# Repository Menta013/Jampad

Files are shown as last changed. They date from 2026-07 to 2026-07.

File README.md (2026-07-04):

# Jampad

Jampad is a compact 3×3 mechanical macropad built around a through-hole
Seeed Studio XIAO RP2040. It includes an EC11 rotary encoder, a 0.91-inch
128×32 OLED, and a single SK6812 MINI-E status LED in a two-piece 3D-printed
enclosure.

## Project images

### Overall assembly and case

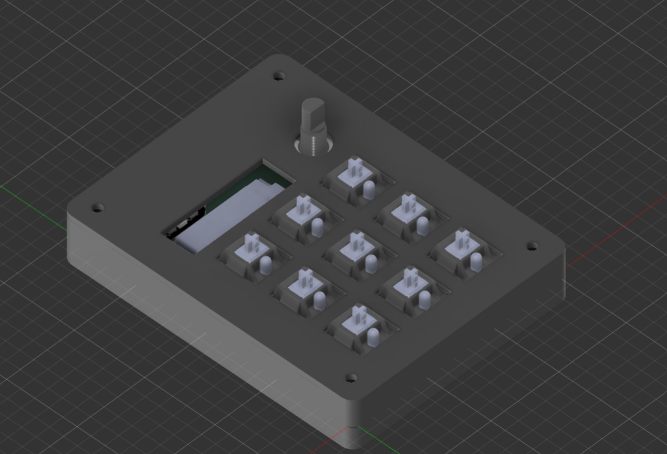
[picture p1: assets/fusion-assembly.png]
Jampad assembly in Fusion 360


### Bottom case

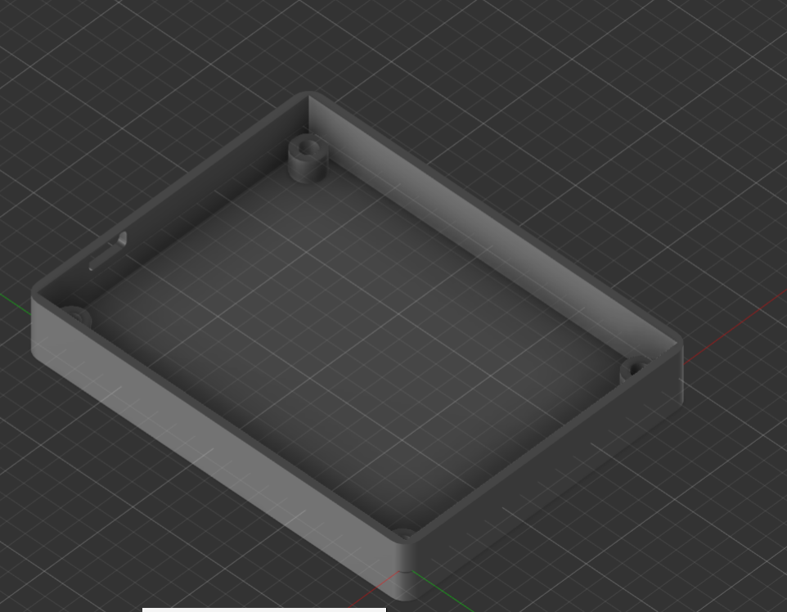
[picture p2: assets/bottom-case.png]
Jampad bottom case


### Top plate

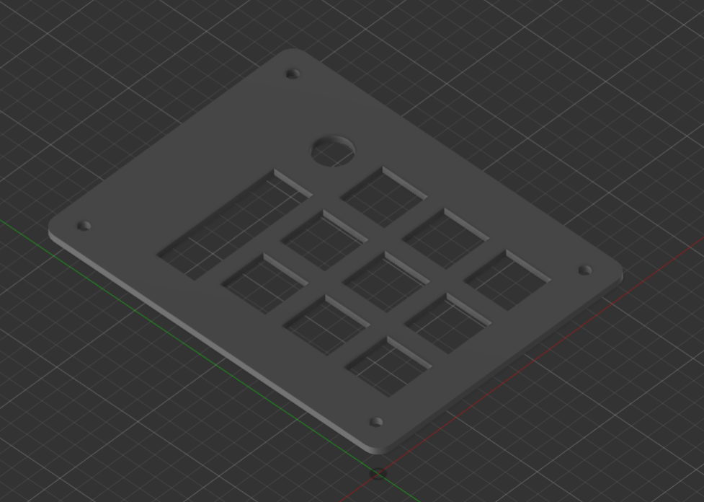
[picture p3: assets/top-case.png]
Jampad top plate


### Schematic

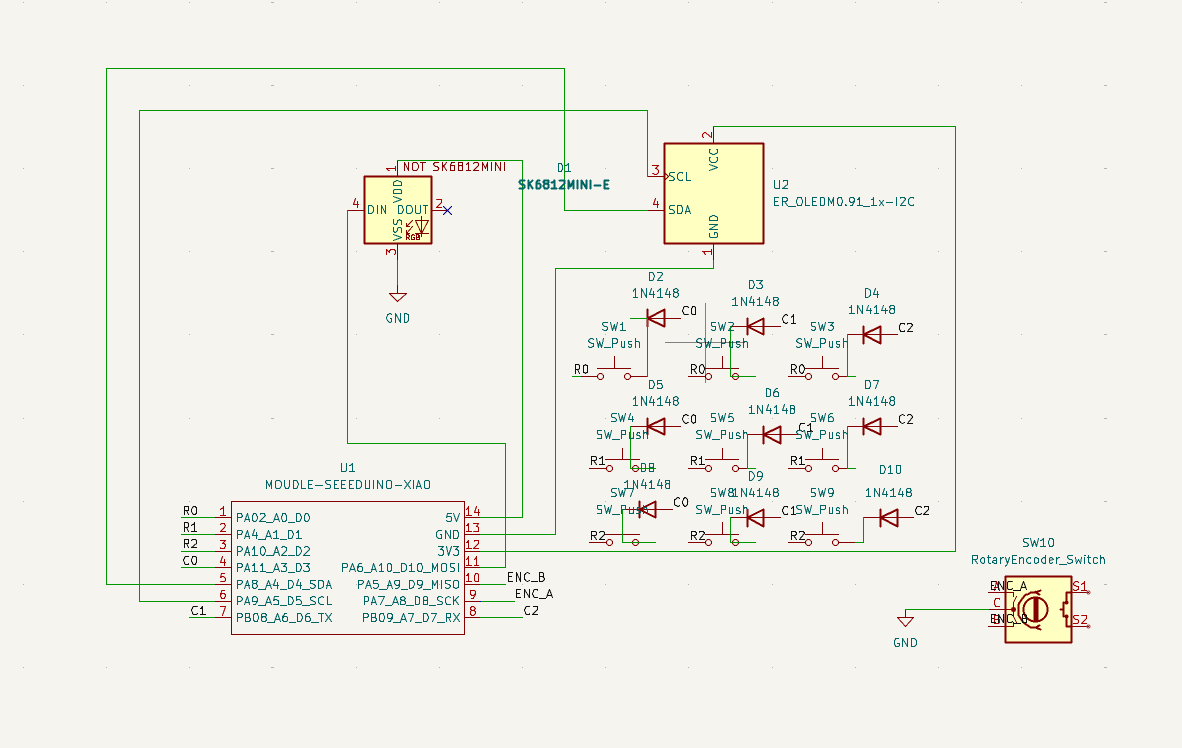
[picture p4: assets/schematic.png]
Jampad schematic


### PCB

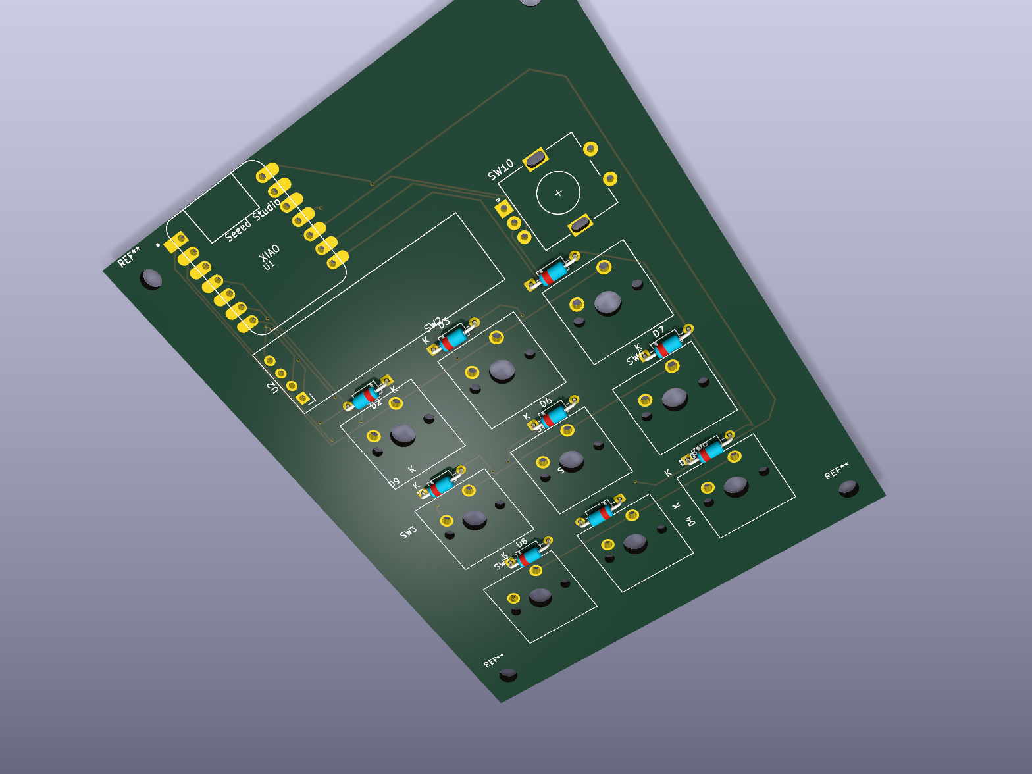
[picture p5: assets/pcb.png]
Jampad PCB render


## Default controls

| Undo | Copy | Paste |
|---|---|---|
| Previous track | Play/Pause | Next track |
| Escape | Windows screenshot | Delete |

The encoder controls system volume:

- Counter-clockwise: volume down
- Clockwise: volume up
- Press: unavailable because the encoder's `S1` and `S2` switch contacts are
  not connected in this PCB revision

## Hardware

- MCU: Seeed Studio XIAO RP2040
- Switches: 9× Cherry MX-compatible switches in a diode-protected 3×3 matrix
- Display: 0.91-inch SSD1306-compatible 128×32 I²C OLED
- Encoder: EC11-style quadrature rotary encoder
- Lighting: 1× SK6812 MINI-E addressable RGB LED
- PCB: two layers, approximately 76.2 × 99.54 mm
- Case: two-piece 3D-printed enclosure

## Firmware pin map

| Function | XIAO pin | RP2040 GPIO |
|---|---:|---:|
| Matrix row 0 | D0 | GP26 |
| Matrix row 1 | D1 | GP27 |
| Matrix row 2 | D2 | GP28 |
| Matrix column 0 | D3 | GP29 |
| OLED SDA | D4 | GP6 |
| OLED SCL | D5 | GP7 |
| Matrix column 1 | D6 | GP0 |
| Matrix column 2 | D7 | GP1 |
| Encoder A | D8 | GP2 |
| Encoder B | D9 | GP4 |
| SK6812 data | D10 | GP3 |

The matrix diode direction is `COL2ROW`.

## Bill of materials

| Quantity | Part | Notes |
|---:|---|---|
| 1 | Seeed Studio XIAO RP2040 | Through-hole mounted |
| 9 | MX-compatible mechanical switches | PCB-mount style |
| 9 | MX-compatible keycaps | 1U |
| 9 | 1N4148 through-hole diodes | Matrix diodes |
| 1 | EC11-style rotary encoder | Rotation is wired; push switch is not |
| 1 | Encoder knob | Sized for the selected shaft |
| 1 | 0.91-inch 128×32 I²C OLED | SSD1306-compatible, four pins |
| 1 | SK6812 MINI-E | Addressable RGB status LED |
| 1 | Custom two-layer PCB | Maximum 100 × 100 mm |
| 1 | 3D-printed top case | Production STEP included |
| 1 | 3D-printed bottom case | Production STEP included |
| 4 | M3×16 mm screws | Confirm final stack height before ordering |
| 4 | M3 heat-set inserts | Approximately 4 mm OD × 5 mm long |

## Repository structure

```text
Jampad_Submission/
├── CAD/          # Full assembly source/export goes here
├── PCB/          # KiCad source files
├── Firmware/     # QMK source
├── production/   # Manufacturing and flash files
└── assets/       # README screenshots
```

## Firmware build

Copy `Firmware/` to `qmk_firmware/keyboards/jampad/`, then run:

```sh
qmk compile -kb jampad -km default
```

The compiled firmware is included as `production/firmware.uf2`.

To flash it, hold the XIAO's **BOOT** button while connecting USB, then copy
`firmware.uf2` to the `RPI-RP2` drive.

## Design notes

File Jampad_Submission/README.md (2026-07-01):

# Jampad

Jampad is a compact 3×3 mechanical macropad built around a through-hole
Seeed Studio XIAO RP2040. It includes an EC11 rotary encoder, a 0.91-inch
128×32 OLED, and a single SK6812 MINI-E status LED in a two-piece 3D-printed
enclosure.

> **Fabrication status:** the nine switch-to-diode connections have been
> repaired. KiCad reports zero unconnected pads and no copper-clearance
> errors. Final Gerbers and drill files are included in
> `production/gerbers.zip`. Review the remaining non-electrical DRC warnings
> in `production/drc_report.txt` before ordering.

## Project images

### Overall assembly and case

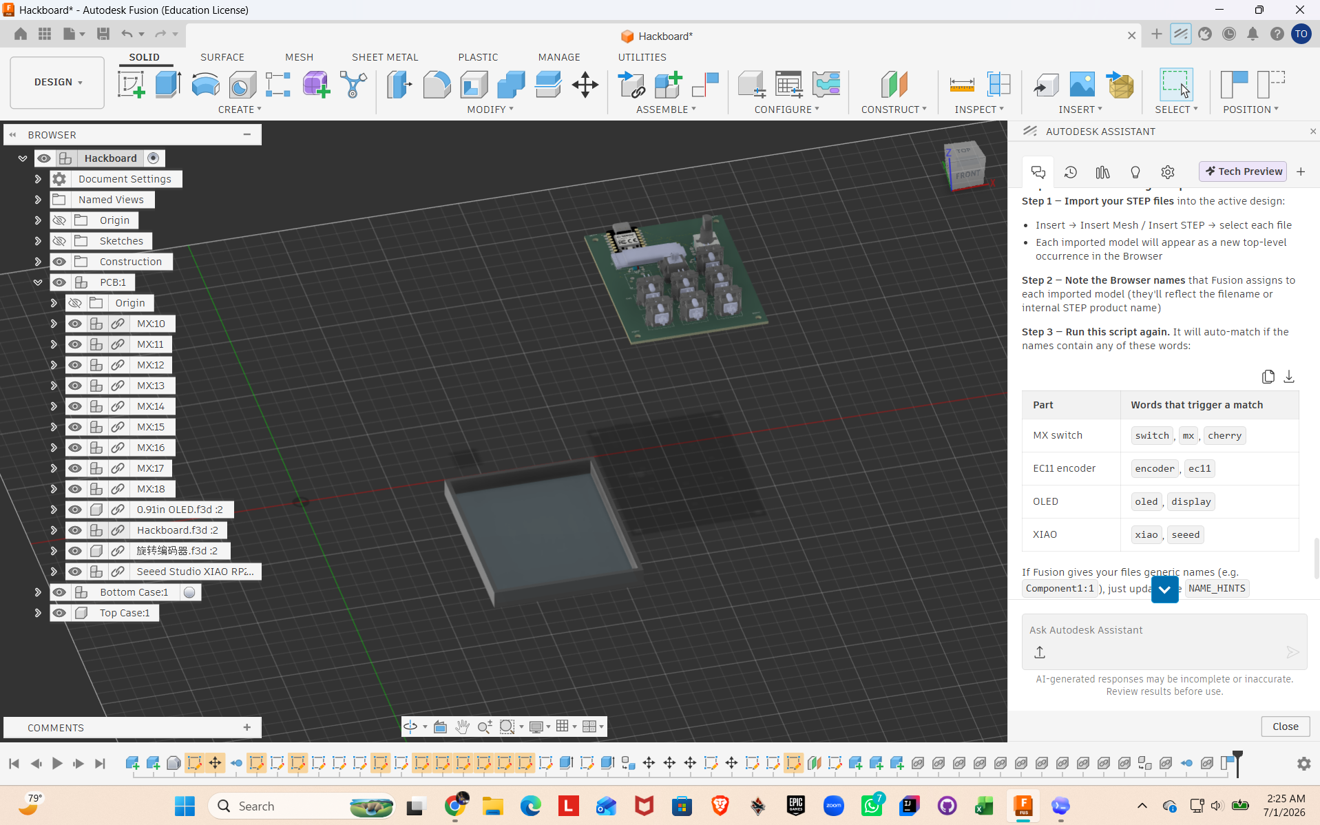
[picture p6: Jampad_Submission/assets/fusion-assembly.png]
Jampad assembly in Fusion 360


### Schematic

Jampad schematic

### PCB

Jampad PCB render

## Default controls

| Undo | Copy | Paste |
|---|---|---|
| Previous track | Play/Pause | Next track |
| Escape | Windows screenshot | Delete |

The encoder controls system volume:

- Counter-clockwise: volume down
- Clockwise: volume up
- Press: unavailable because the encoder's `S1` and `S2` switch contacts are
  not connected in this PCB revision

## Hardware

- MCU: Seeed Studio XIAO RP2040
- Switches: 9× Cherry MX-compatible switches in a diode-protected 3×3 matrix
- Display: 0.91-inch SSD1306-compatible 128×32 I²C OLED
- Encoder: EC11-style quadrature rotary encoder
- Lighting: 1× SK6812 MINI-E addressable RGB LED
- PCB: two layers, approximately 76.2 × 99.54 mm
- Case: two-piece 3D-printed enclosure

## Firmware pin map

| Function | XIAO pin | RP2040 GPIO |
|---|---:|---:|
| Matrix row 0 | D0 | GP26 |
| Matrix row 1 | D1 | GP27 |
| Matrix row 2 | D2 | GP28 |
| Matrix column 0 | D3 | GP29 |
| OLED SDA | D4 | GP6 |
| OLED SCL | D5 | GP7 |
| Matrix column 1 | D6 | GP0 |
| Matrix column 2 | D7 | GP1 |
| Encoder A | D8 | GP2 |
| Encoder B | D9 | GP4 |
| SK6812 data | D10 | GP3 |

The matrix diode direction is `COL2ROW`.

## Bill of materials

| Quantity | Part | Notes |
|---:|---|---|
| 1 | Seeed Studio XIAO RP2040 | Through-hole mounted |
| 9 | MX-compatible mechanical switches | PCB-mount style |
| 9 | MX-compatible keycaps | 1U |
| 9 | 1N4148 through-hole diodes | Matrix diodes |
| 1 | EC11-style rotary encoder | Rotation is wired; push switch is not |
| 1 | Encoder knob | Sized for the selected shaft |
| 1 | 0.91-inch 128×32 I²C OLED | SSD1306-compatible, four pins |
| 1 | SK6812 MINI-E | Addressable RGB status LED |
| 1 | Custom two-layer PCB | Maximum 100 × 100 mm |
| 1 | 3D-printed top case | Production STEP included |
| 1 | 3D-printed bottom case | Production STEP included |
| 4 | M3×16 mm screws | Confirm final stack height before ordering |
| 4 | M3 heat-set inserts | Approximately 4 mm OD × 5 mm long |

## Repository structure

```text
Jampad_Submission/
├── CAD/          # Full assembly source/export goes here
├── PCB/          # KiCad source files
├── Firmware/     # QMK source
├── production/   # Manufacturing and flash files
└── assets/       # README screenshots
```

## Firmware build

Copy `Firmware/` to `qmk_firmware/keyboards/jampad/`, then run:

```sh
qmk compile -kb jampad -km default
```

The compiled firmware is included as `production/firmware.uf2`.

To flash it, hold the XIAO's **BOOT** button while connecting USB, then copy
`firmware.uf2` to the `RPI-RP2` drive.

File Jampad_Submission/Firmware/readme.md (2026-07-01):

# Jampad QMK firmware

Starter QMK firmware for the 3x3 Jampad using a Seeed Studio XIAO RP2040.

## Hardware map

| Function | XIAO pin | RP2040 GPIO |
|---|---:|---:|
| Matrix row 0 | D0 | GP26 |
| Matrix row 1 | D1 | GP27 |
| Matrix row 2 | D2 | GP28 |
| Matrix column 0 | D3 | GP29 |
| OLED SDA | D4 | GP6 |
| OLED SCL | D5 | GP7 |
| Matrix column 1 | D6 | GP0 |
| Matrix column 2 | D7 | GP1 |
| Encoder A | D8 | GP2 |
| Encoder B | D9 | GP4 |
| SK6812 data | D10 | GP3 |

The matrix diodes are configured `COL2ROW`.

## Default controls

| Undo | Copy | Paste |
|---|---|---|
| Previous track | Play/Pause | Next track |
| Escape | Windows screenshot | Delete |

Turning the encoder controls system volume.

## Build

Copy this `jampad_qmk` folder into:

    qmk_firmware/keyboards/jampad

Then run from the QMK firmware directory:

    qmk compile -kb jampad -km default

The resulting `.uf2` file will be placed in the QMK firmware root.

## Flash

1. Disconnect the XIAO.
2. Hold its **BOOT** button.
3. Connect USB while continuing to hold BOOT.
4. Release BOOT when the `RPI-RP2` drive appears.
5. Copy the compiled `.uf2` file onto that drive.

## Hardware notes

- The encoder push-button pins S1 and S2 are unconnected in the supplied
  schematic and PCB. Rotation works; pressing the knob cannot be detected.
- The SK6812 is powered from 5 V while its data signal is 3.3 V. This often
  works for a short trace and one LED, but it is outside the most conservative
  logic-level margin. If the LED flickers or fails, use a 3.3-to-5 V level
  shifter or power the LED from 3.3 V if its specific part permits it.
- If the encoder direction is reversed, swap `pin_a` and `pin_b` in
  `keyboard.json`.
- If one encoder detent changes volume more than once, change its `resolution`
  from `4` to `2` in `keyboard.json`.

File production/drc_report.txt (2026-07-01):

** Drc report for Hackboard_v1.kicad_pcb **
** Created on 2026-07-01T11:00:50 **
** Report includes: Errors, Warnings, Exclusions **

** Found 51 DRC violations **
[via_dangling]: Via is not connected or connected on only one layer
    Local override; warning
    @(116.0000 mm, 42.5350 mm): Via [Net-(D1-VDD)] on F.Cu - B.Cu
[silk_edge_clearance]: Silkscreen clipped by board edge
    Rule: board setup constraints silk; warning
    @(76.2000 mm, 30.0000 mm): Rectangle on Edge.Cuts
    @(92.0200 mm, 36.0493 mm): Segment of U1 on F.Silkscreen
[silk_edge_clearance]: Silkscreen clipped by board edge
    Rule: board setup constraints silk; warning
    @(76.2000 mm, 30.0000 mm): Rectangle on Edge.Cuts
    @(101.0200 mm, 28.6960 mm): Segment of U1 on F.Silkscreen
[holes_co_located]: Drilled holes co-located
    Local override; warning
    @(91.4400 mm, 70.4950 mm): Via [Net-(D2-K)] on F.Cu - B.Cu
    @(91.4400 mm, 70.4950 mm): Via [Net-(D2-K)] on F.Cu - B.Cu
[holes_co_located]: Drilled holes co-located
    Local override; warning
    @(91.4400 mm, 111.7600 mm): Via [Net-(D8-K)] on F.Cu - B.Cu
    @(91.4400 mm, 111.7600 mm): PTH pad 2 [Net-(D8-K)] of SW7
[holes_co_located]: Drilled holes co-located
    Local override; warning
    @(91.4400 mm, 111.7600 mm): Via [Net-(D8-K)] on F.Cu - B.Cu
    @(91.4400 mm, 111.7600 mm): PTH pad 2 [Net-(D8-K)] of SW7
[lib_footprint_mismatch]: Footprint 'SK6812MINI-E_fixed' does not match copy in library 'footprints'
    Local override; warning
    @(123.1900 mm, 104.9928 mm): Footprint D1
[silk_overlap]: Silkscreen clearance
    Rule: board setup constraints silk; warning
    @(88.2650 mm, 83.1850 mm): Segment of SW1 on F.Silkscreen
    @(88.9000 mm, 82.1300 mm): Reference field of D9
[silk_overlap]: Silkscreen clearance
    Rule: board setup constraints silk; warning
    @(93.9700 mm, 85.2400 mm): Segment of D5 on F.Silkscreen
    @(95.2500 mm, 87.3760 mm): Reference field of SW4
[silk_overlap]: Silkscreen clearance
    Rule: board setup constraints silk; warning
    @(95.2500 mm, 87.3760 mm): Reference field of SW4
    @(93.8500 mm, 85.2400 mm): Segment of D5 on F.Silkscreen
[silk_overlap]: Silkscreen clearance
    Rule: board setup constraints silk; warning
    @(95.2500 mm, 87.3760 mm): Reference field of SW4
    @(93.1300 mm, 85.2400 mm): Rectangle of D5 on F.Silkscreen
[silk_overlap]: Silkscreen clearance
    Rule: board setup constraints silk; warning
    @(131.2300 mm, 104.2900 mm): Rectangle of D10 on F.Silkscreen
    @(132.1200 mm, 104.8760 mm): Reference field of SW9
[silk_overlap]: Silkscreen clearance
    Rule: board setup constraints silk; warning
    @(129.5400 mm, 105.4100 mm): Reference field of D10
    @(132.1200 mm, 104.8760 mm): Reference field of SW9
[silk_overlap]: Silkscreen clearance
    Rule: board setup constraints silk; warning
    @(132.1200 mm, 104.8760 mm): Reference field of SW9
    @(130.5800 mm, 105.4100 mm): Segment of D10 on F.Silkscreen
[silk_overlap]: Silkscreen clearance
    Rule: board setup constraints silk; warning
    @(132.1200 mm, 104.8760 mm): Reference field of SW9
    @(131.8300 mm, 104.2900 mm): Segment of D10 on F.Silkscreen
[silk_overlap]: Silkscreen clearance
    Rule: board setup constraints silk; warning
    @(131.9500 mm, 104.2900 mm): Segment of D10 on F.Silkscreen
    @(132.1200 mm, 104.8760 mm): Reference field of SW9
[silk_overlap]: Silkscreen clearance
    Rule: board setup constraints silk; warning
    @(132.0700 mm, 104.2900 mm): Segment of D10 on F.Silkscreen
    @(132.1200 mm, 104.8760 mm): Reference field of SW9
[silk_overlap]: Silkscreen clearance
    Rule: board setup constraints silk; warning
    @(114.3000 mm, 87.3760 mm): Reference field of SW5
    @(114.7200 mm, 85.2400 mm): Rectangle of D6 on F.Silkscreen
[silk_overlap]: Silkscreen clearance
    Rule: board setup constraints silk; warning
    @(114.3000 mm, 87.3760 mm): Reference field of SW5
    @(115.3200 mm, 85.2400 mm): Segment of D6 on F.Silkscreen
[silk_overlap]: Silkscreen clearance
    Rule: board setup constraints silk; warning
    @(114.3000 mm, 87.3760 mm): Reference field of SW5
    @(115.4400 mm, 85.2400 mm): Segment of D6 on F.Silkscreen
[silk_overlap]: Silkscreen clearance
    Rule: board setup constraints silk; warning
    @(114.3000 mm, 87.3760 mm): Reference field of SW5
    @(115.5600 mm, 85.2400 mm): Segment of D6 on F.Silkscreen
[silk_overlap]: Silkscreen clearance
    Rule: board setup constraints silk; warning
    @(111.7600 mm, 64.7700 mm): Reference field of D3
    @(110.3800 mm, 64.0860 mm): Reference field of SW2
[silk_overlap]: Silkscreen clearance
    Rule: board setup constraints silk; warning
    @(85.1400 mm, 64.4200 mm): Rectangle of U2 on F.Silkscreen
    @(110.3800 mm, 64.0860 mm): Reference field of SW2
[silk_overlap]: Silkscreen clearance
    Rule: board setup constraints silk; warning
    @(85.1400 mm, 64.4200 mm): Rectangle of U2 on F.Silkscreen
    @(111.7600 mm, 64.7700 mm): Reference field of D3
[silk_overlap]: Silkscreen clearance
    Rule: board setup constraints silk; warning
    @(95.2500 mm, 68.3260 mm): Reference field of SW1
    @(97.3700 mm, 68.4300 mm): Rectangle of D2 on F.Silkscreen
[silk_overlap]: Silkscreen clearance
    Rule: board setup constraints silk; warning
    @(88.2650 mm, 69.2150 mm): Segment of SW1 on F.Silkscreen
    @(95.2500 mm, 69.4300 mm): Reference field of D2
[silk_overlap]: Silkscreen clearance
    Rule: board setup constraints silk; warning
    @(88.2650 mm, 69.2150 mm): Segment of SW1 on F.Silkscreen
    @(99.0600 mm, 69.1100 mm): Footprint text of D2 (K)
[silk_overlap]: Silkscreen clearance
    Rule: board setup constraints silk; warning
    @(129.5400 mm, 105.4100 mm): Reference field of D10
    @(130.5800 mm, 105.4100 mm): Segment of D10 on F.Silkscreen
[silk_over_copper]: Silkscreen clipped by solder mask
    Local override; warning
    @(91.4400 mm, 86.3600 mm): Reference field of D5
    @(91.4400 mm, 86.3600 mm): PTH pad 1 [Net-(D5-K)] of D5
[silk_over_copper]: Silkscreen clipped by solder mask
    Local override; warning
    @(132.1200 mm, 85.8260 mm): Reference field of SW6
    @(133.3500 mm, 86.3600 mm): PTH pad 1 [Net-(D7-K)] of D7
[silk_over_copper]: Silkscreen clipped by solder mask
    Local override; warning
    @(94.0200 mm, 104.8760 mm): Reference field of SW7
    @(95.2500 mm, 105.4100 mm): PTH pad 1 [Net-(D8-K)] of D8
[silk_over_copper]: Silkscreen clipped by solder mask
    Local override; warning
    @(113.0700 mm, 95.5560 mm): Reference field of SW8
    @(114.3000 mm, 95.2500 mm): NPTH pad of SW5
[silk_over_copper]: Silkscreen clipped by solder mask
    Local override; warning
    @(114.3000 mm, 87.3760 mm): Reference field of SW5
    @(113.0300 mm, 86.3600 mm): PTH pad 1 [Net-(D6-K)] of D6
[silk_over_copper]: Silkscreen clipped by solder mask
    Local override; warning
    @(129.5400 mm, 105.4100 mm): Reference field of D10
    @(129.5400 mm, 105.4100 mm): PTH pad 1 [Net-(D10-K)] of D10
[silk_over_copper]: Silkscreen clipped by solder mask
    Local override; warning
    @(89.6649 mm, 49.0751 mm): Arc of U1 on F.Silkscreen
    @(88.8950 mm, 48.2400 mm): PTH pad 7 [/C1] of U1
[silk_over_copper]: Silkscreen clipped by solder mask
    Local override; warning
    @(103.4200 mm, 49.1200 mm): Arc of U1 on F.Silkscreen
    @(104.1450 mm, 48.2400 mm): PTH pad 8 [/C2] of U1
[silk_over_copper]: Silkscreen clipped by solder mask
    Local override; warning
    @(103.3754 mm, 32.1646 mm): Arc of U1 on F.Silkscreen
    @(104.1450 mm, 33.0000 mm): PTH pad 14 [Net-(D1-VDD)] of U1
[silk_over_copper]: Silkscreen clipped by solder mask
    Local override; warning
    @(87.6200 mm, 32.1200 mm): Segment of U1 on F.Silkscreen
    @(88.8950 mm, 45.7000 mm): PTH pad 6 [Net-(U1-PA9_A5_D5_SCL)] of U1
[silk_over_copper]: Silkscreen clipped by solder mask
    Local override; warning
    @(87.6200 mm, 32.1200 mm): Segment of U1 on F.Silkscreen
    @(88.8950 mm, 48.2400 mm): PTH pad 7 [/C1] of U1
[silk_over_copper]: Silkscreen clipped by solder mask
    Local override; warning
    @(87.6200 mm, 32.1200 mm): Segment of U1 on F.Silkscreen
    @(88.8950 mm, 33.0000 mm): PTH pad 1 [/R0] of U1
[silk_over_copper]: Silkscreen clipped by solder mask
    Local override; warning
    @(87.6200 mm, 32.1200 mm): Segment of U1 on F.Silkscreen
    @(88.8950 mm, 35.5400 mm): PTH pad 2 [/R1] of U1
[silk_over_copper]: Silkscreen clipped by solder mask
    Local override; warning
    @(87.6200 mm, 32.1200 mm): Segment of U1 on F.Silkscreen
    @(88.8950 mm, 38.0800 mm): PTH pad 3 [/R2] of U1
[silk_over_copper]: Silkscreen clipped by solder mask
    Local override; warning
    @(87.6200 mm, 32.1200 mm): Segment of U1 on F.Silkscreen
    @(88.8950 mm, 40.6200 mm): PTH pad 4 [/C0] of U1
[silk_over_copper]: Silkscreen clipped by solder mask
    Local override; warning
    @(87.6200 mm, 32.1200 mm): Segment of U1 on F.Silkscreen
    @(88.8950 mm, 43.1600 mm): PTH pad 5 [Net-(U1-PA8_A4_D4_SDA)] of U1
[silk_over_copper]: Silkscreen clipped by solder mask
    Local override; warning
    @(105.4200 mm, 49.1200 mm): Segment of U1 on F.Silkscreen
    @(104.1450 mm, 48.2400 mm): PTH pad 8 [/C2] of U1
[silk_over_copper]: Silkscreen clipped by solder mask
    Local override; warning
    @(105.4200 mm, 49.1200 mm): Segment of U1 on F.Silkscreen
    @(104.1450 mm, 45.7000 mm): PTH pad 9 [/ENC_A] of U1
[silk_over_copper]: Silkscreen clipped by solder mask
    Local override; warning
    @(105.4200 mm, 49.1200 mm): Segment of U1 on F.Silkscreen
    @(104.1450 mm, 43.1600 mm): PTH pad 10 [/ENC_B] of U1
[silk_over_copper]: Silkscreen clipped by solder mask
    Local override; warning
    @(105.4200 mm, 49.1200 mm): Segment of U1 on F.Silkscreen
    @(104.1450 mm, 40.6200 mm): PTH pad 11 [Net-(D1-DIN)] of U1
[silk_over_copper]: Silkscreen clipped by solder mask
    Local override; warning
    @(105.4200 mm, 49.1200 mm): Segment of U1 on F.Silkscreen
    @(104.1450 mm, 38.0800 mm): PTH pad 12 [Net-(U1-3V3)] of U1
[silk_over_copper]: Silkscreen clipped by solder mask
    Local override; warning
    @(105.4200 mm, 49.1200 mm): Segment of U1 on F.Silkscreen
    @(104.1450 mm, 35.5400 mm): PTH pad 13 [Net-(U1-GND)] of U1
[silk_over_copper]: Silkscreen clipped by solder mask
    Local override; warning
    @(105.4200 mm, 49.1200 mm): Segment of U1 on F.Silkscreen
    @(104.1450 mm, 33.0000 mm): PTH pad 14 [Net-(D1-VDD)] of U1

** Found 0 unconnected pads **

** Found 7 Footprint errors **
[duplicate_footprints]: Duplicate footprints
    Local override; warning
    @(81.0000 mm, 125.0000 mm): Footprint REF**
    @(148.0000 mm, 125.0000 mm): Footprint REF**
[duplicate_footprints]: Duplicate footprints
    Local override; warning
    @(148.0000 mm, 35.0000 mm): Footprint REF**
    @(148.0000 mm, 125.0000 mm): Footprint REF**
[duplicate_footprints]: Duplicate footprints
    Local override; warning
    @(81.0000 mm, 35.0000 mm): Footprint REF**
    @(148.0000 mm, 125.0000 mm): Footprint REF**
[extra_footprint]: Extra footprint
    Local override; warning
    @(148.0000 mm, 125.0000 mm): Footprint REF**
[extra_footprint]: Extra footprint
    Local override; warning
    @(81.0000 mm, 125.0000 mm): Footprint REF**
[extra_footprint]: Extra footprint
    Local override; warning
    @(148.0000 mm, 35.0000 mm): Footprint REF**
[extra_footprint]: Extra footprint
    Local override; warning
    @(81.0000 mm, 35.0000 mm): Footprint REF**

** Ignored checks **
    - Footprint has no courtyard defined
    - Track endpoint not centered on via
    - Tuning profile track geometries
    - Footprint doesn't match symbol's footprint filters
    - Footprint component type doesn't match footprint pads

** End of Report **

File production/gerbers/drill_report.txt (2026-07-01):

Drill report for Hackboard_v1.kicad_pcb
Created on 2026-07-01T11:01:47

Copper Layer Stackup:
    =============================================================
    L1 :  F.Cu                      front
    L2 :  B.Cu                      back

Drill file 'Hackboard_v1-PTH.drl' contains
    plated through holes:
    =============================================================
    T1  0.300mm  0.0118"  (20 holes))
    T2  0.800mm  0.0315"  (18 holes))
    T3  1.000mm  0.0394"  (23 holes))
    T4  1.500mm  0.0591"  (20 holes)  (with 2 slots)

    Total plated holes count 81

Drill file 'Hackboard_v1-NPTH.drl' contains
    unplated through holes:
    =============================================================
    T1  1.700mm  0.0669"  (18 holes))
    T2  3.200mm  0.1260"  (4 holes))
    T3  4.000mm  0.1575"  (9 holes))

    Total unplated holes count 31

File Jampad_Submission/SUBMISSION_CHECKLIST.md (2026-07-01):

# Jampad submission checklist

## Source files

- [x] `PCB/` contains `.kicad_pro`, `.kicad_sch`, and `.kicad_pcb`
- [x] `Firmware/` contains the complete QMK source
- [x] `CAD/` contains the PCB mechanical STEP
- [x] Export the complete assembled Fusion design to
  `CAD/Jampad_Complete_Assembly.step`

## Production files

- [x] Compiled QMK firmware saved as `production/firmware.uf2`
- [x] Repair the nine diode net/routing issues
- [x] Re-run PCB DRC and schematic parity
- [x] Create `production/gerbers.zip`
- [x] Export `production/Top.step`
- [x] Export `production/Bottom.step`

## README

- [x] Overall assembly/case screenshot
- [x] Schematic screenshot
- [x] PCB render
- [x] BOM
- [x] Description and controls
- [ ] Replace screenshots with final polished views if desired

## Publishing

- [ ] Create a GitHub repository
- [ ] Copy this project into the cloned repository
- [ ] Commit and push the files
- [ ] Make the ship post in `#hackpad-ships`
- [ ] Complete the submission form

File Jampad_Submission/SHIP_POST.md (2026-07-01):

Hackpad name: Jampad

GitHub Repo: <add repository URL>

Description: Jampad is a compact 3×3 mechanical macropad powered by a
through-hole Seeed Studio XIAO RP2040. It has a rotary volume encoder, a
0.91-inch OLED, an addressable RGB status LED, and a custom two-piece
3D-printed enclosure. Its default layer provides editing shortcuts, media
controls, Escape, Windows screenshot, and Delete.

Attach:

- `assets/fusion-assembly.png`
- `assets/schematic.png`
- `assets/pcb.png`

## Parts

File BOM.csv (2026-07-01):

Item | Description | Quantity | Unit Cost USD | Total Cost USD | Notes
Microcontroller | Seeed Studio XIAO RP2040 | 1 | 5.40 | 5.40 | Through-hole mounted main controller
PCB manufacturing | Two-layer Jampad PCB fabrication | 1 | 10.00 | 10.00 | Approximately 76.2 x 99.54 mm
Case fabrication | 3D-printed top and bottom enclosure | 1 | 8.00 | 8.00 | Printed from the included STEP files
Mechanical switches | MX-compatible PCB-mount switches | 9 | 0.50 | 4.50 | One per key
Keycaps | MX-compatible 1U keycaps | 9 | 0.50 | 4.50 | One per switch
Matrix diodes | 1N4148 through-hole diodes | 9 | 0.05 | 0.45 | One per switch
OLED display | 0.91-inch 128x32 I2C OLED | 1 | 3.00 | 3.00 | SSD1306-compatible
Rotary encoder | EC11-style encoder | 1 | 1.50 | 1.50 | Rotation input
Encoder knob | Knob matching encoder shaft | 1 | 1.00 | 1.00
RGB LED | SK6812 MINI-E addressable LED | 1 | 0.50 | 0.50 | Status lighting
Screws | M3 x 16 mm screws | 4 | 0.25 | 1.00 | Confirm final stack height
Heat-set inserts | M3 inserts approximately 4 mm OD x 5 mm | 4 | 0.25 | 1.00
USB cable | USB-C data cable | 1 | 3.00 | 3.00 | Programming and normal use
Shipping and tax | Estimated fulfillment costs | 1 | 6.15 | 6.15
TOTAL |  |  |  | 50.00

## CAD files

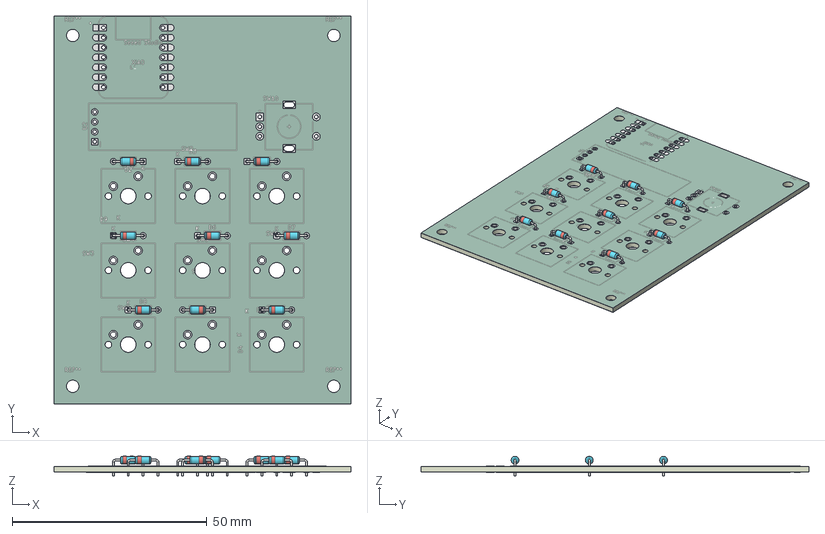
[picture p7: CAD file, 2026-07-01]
Jampad_Submission/CAD/Jampad_PCB_Assembly.step
76.2 x 99.5 x 5.01 mm
D_DO-35_SOD27_P7.62mm_Horizontal x 9
Hackboard_v1_copper
Hackboard_v1_pad
Hackboard_v1_via
Hackboard_v1_silkscreen x 2
Hackboard_v1_soldermask x 2
Hackboard_v1_PCB

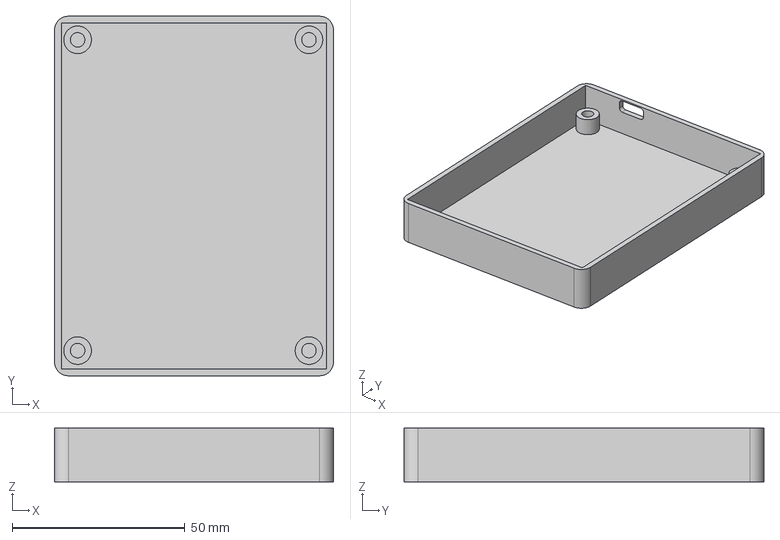
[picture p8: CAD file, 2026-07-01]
production/Bottom.step
80.8 x 104.1 x 15.5 mm

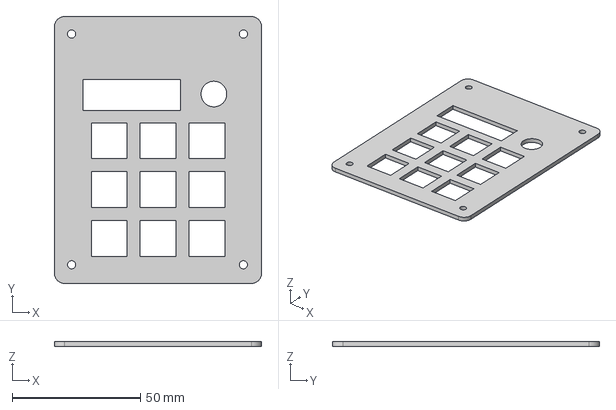
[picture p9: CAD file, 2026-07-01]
production/Top.step
80.8 x 104.1 x 2.00 mm

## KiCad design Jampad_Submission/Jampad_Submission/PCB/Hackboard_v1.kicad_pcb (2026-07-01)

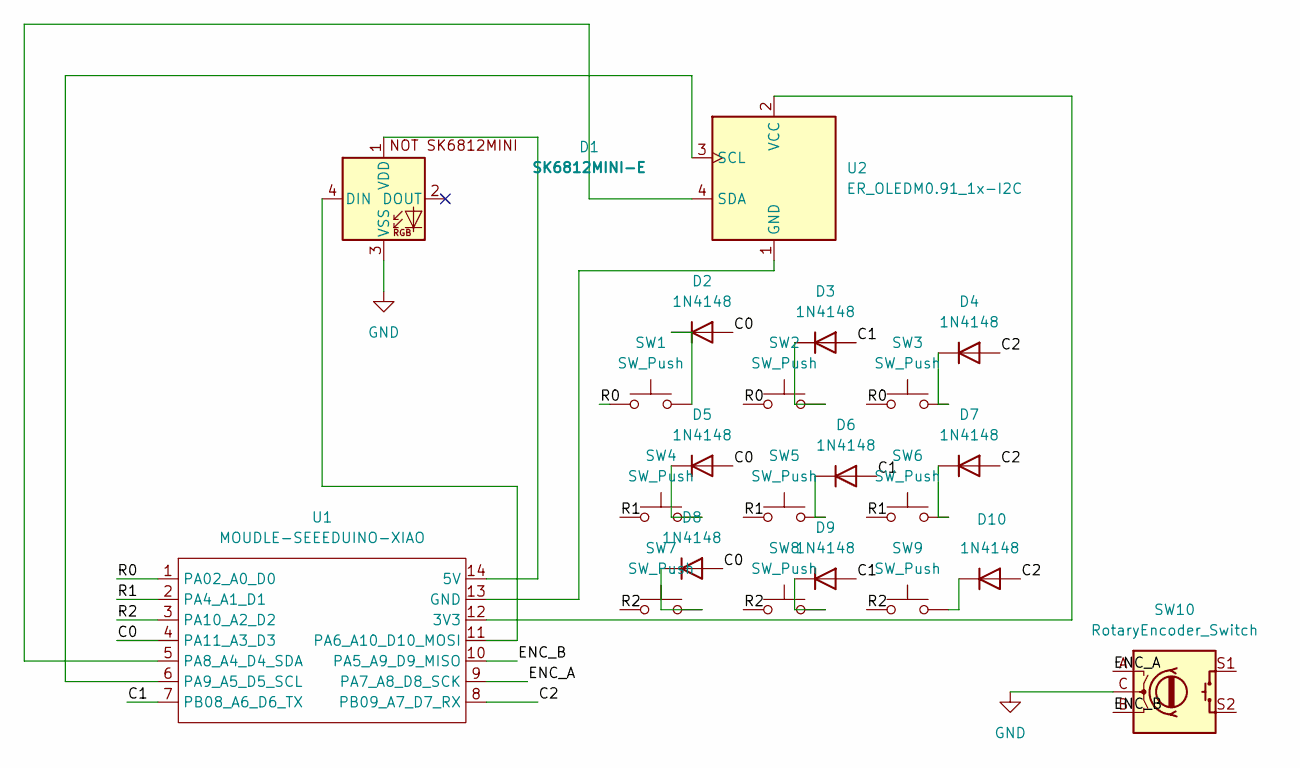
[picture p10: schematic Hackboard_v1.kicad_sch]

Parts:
D1: SK6812MINI-E; SK6812MINI-E_fixed
D2, D3, D4, D5, D6, D7, D8, D9, D10: 1N4148; D_DO-35_SOD27_P7.62mm_Horizontal
SW1, SW2, SW3, SW4, SW5, SW6, SW7, SW8, SW9: SW_Push; SW_Cherry_MX_1.00u_PCB
SW10: RotaryEncoder_Switch; RotaryEncoder_Alps_EC11E-Switch_Vertical_H20mm
U1: MOUDLE-SEEEDUINO-XIAO; XIAO-Generic-Hybrid-14P-2.54-21X17.8MM
U2: ER_OLEDM0.91_1x-I2C

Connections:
/C0: D2.2 (A), D5.2 (A), D8.2 (A), U1.4 (PA11_A3_D3)
/C1: D3.2 (A), D6.2 (A), D9.2 (A), U1.7 (PB08_A6_D6_TX)
/C2: D4.2 (A), D7.2 (A), D10.2 (A), U1.8 (PB09_A7_D7_RX)
/ENC_A: SW10.A, U1.9 (PA7_A8_D8_SCK)
/ENC_B: SW10.B, U1.10 (PA5_A9_D9_MISO)
/R0: SW1.1, SW2.1, SW3.1, U1.1 (PA02_A0_D0)
/R1: SW4.1, SW5.1, SW6.1, U1.2 (PA4_A1_D1)
/R2: SW7.1, SW8.1, SW9.1, U1.3 (PA10_A2_D2)
GND: D1.3 (VSS), SW10.C
unnamed: D1.4 (DIN), U1.11 (PA6_A10_D10_MOSI)
unnamed: D1.1 (VDD), U1.14 (5V)
unnamed: D2.1 (K), SW1.2
unnamed: D3.1 (K), SW2.2
unnamed: D4.1 (K), SW3.2
unnamed: D5.1 (K), SW4.2
unnamed: D6.1 (K), SW5.2
unnamed: D7.1 (K), SW6.2
unnamed: D8.1 (K), SW7.2
unnamed: D9.1 (K), SW8.2
unnamed: D10.1 (K), SW9.2
unnamed: U1.12 (3V3), U2.2 (VCC)
unnamed: U1.13 (GND), U2.1 (GND)
unnamed: U1.5 (PA8_A4_D4_SDA), U2.4 (SDA)
unnamed: U1.6 (PA9_A5_D5_SCL), U2.3 (SCL)

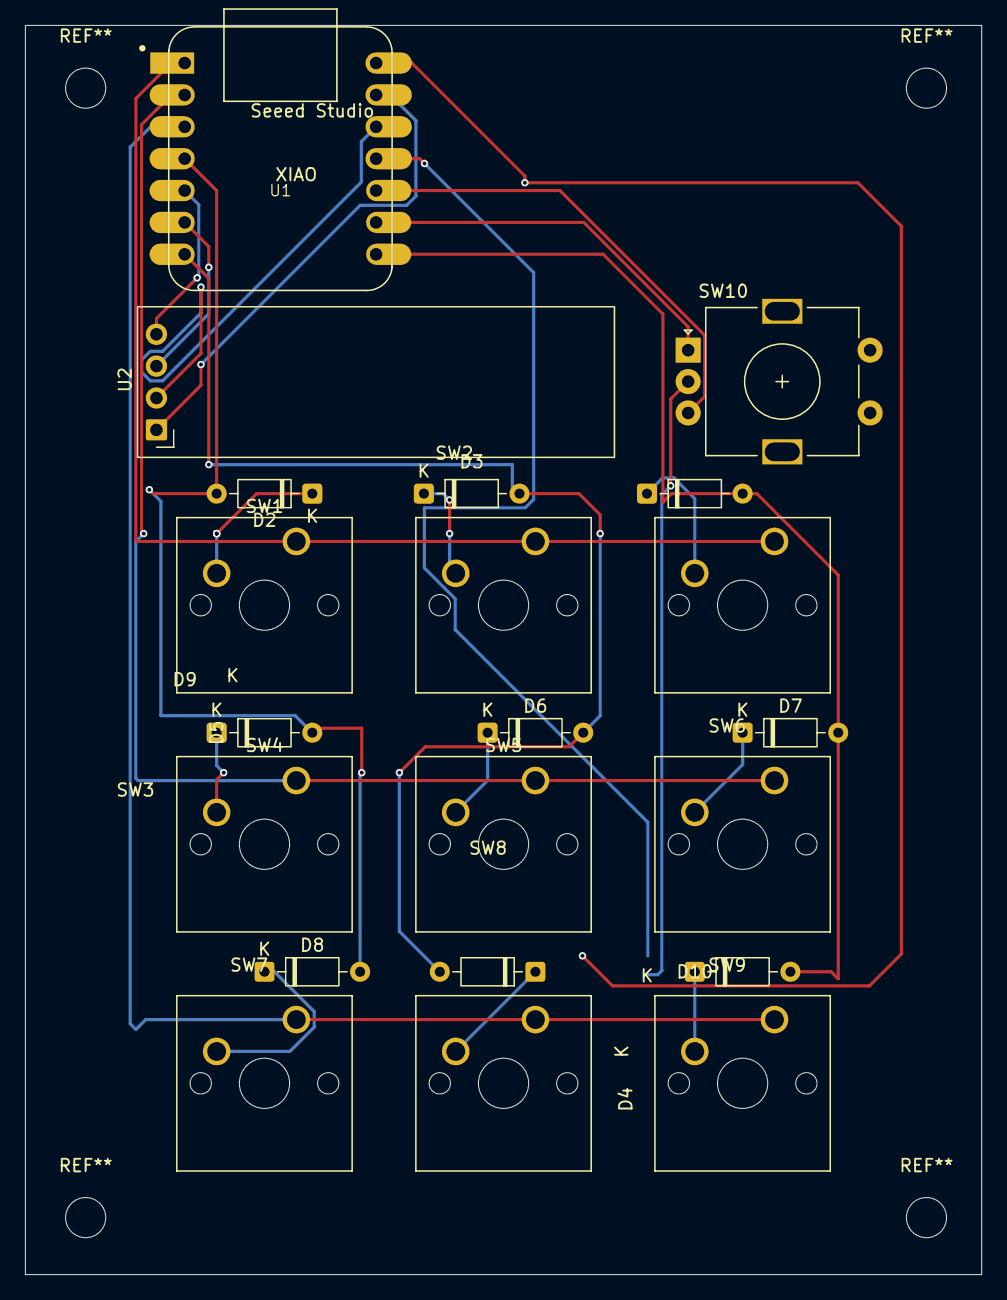
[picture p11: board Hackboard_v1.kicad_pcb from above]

Board: 2 copper layers, 76.2 x 99.5 mm, 22 parts (0 on the bottom side), 24 nets.

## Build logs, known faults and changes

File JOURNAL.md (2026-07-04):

# Jampad Build Journal

## Project overview

Jampad is a compact 3×3 mechanical macropad powered by a through-hole Seeed Studio XIAO RP2040. It includes nine MX-compatible switches, a rotary encoder, a 0.91-inch OLED, one addressable RGB LED, QMK firmware, and a custom two-piece 3D-printed enclosure.

## June 28, 2026 — Initial design

I started by defining the main features and laying out the first schematic in KiCad. I chose the XIAO RP2040 because it is compact, supports USB HID, and has enough GPIO for the switch matrix, OLED, encoder, and RGB LED.

The initial electrical design included:

- A 3×3 switch matrix
- Nine 1N4148 matrix diodes
- An EC11-style rotary encoder
- A 128×32 I²C OLED
- An SK6812 MINI-E status LED
- Four M3 mounting holes

## June 29, 2026 — PCB and component models

I assigned footprints, placed the components, and routed the two-layer PCB. The finished board is approximately 76.2 × 99.54 mm, keeping it below the program's 100 × 100 mm limit.

I also gathered 3D models for the XIAO RP2040, MX switches, OLED, and encoder so I could inspect the complete assembly mechanically before manufacturing.

## June 30, 2026 — Enclosure design

I exported the PCB as a STEP model and brought the electronics into Fusion 360. I designed a two-piece enclosure consisting of:

- A bottom case with PCB mounting standoffs and a USB-C opening
- A top plate with nine switch cutouts
- An OLED window
- An encoder-shaft opening
- Four M3 assembly holes

I adjusted the component and case alignment using rigid groups, projected geometry, and the Align tool. The top and bottom pieces were then exported separately for 3D printing.

## July 1, 2026 — Firmware

I created QMK firmware for the XIAO RP2040. The hardware pin map is:

| Function | XIAO pin | RP2040 GPIO |
|---|---:|---:|
| Matrix row 0 | D0 | GP26 |
| Matrix row 1 | D1 | GP27 |
| Matrix row 2 | D2 | GP28 |
| Matrix column 0 | D3 | GP29 |
| OLED SDA | D4 | GP6 |
| OLED SCL | D5 | GP7 |
| Matrix column 1 | D6 | GP0 |
| Matrix column 2 | D7 | GP1 |
| Encoder A | D8 | GP2 |
| Encoder B | D9 | GP4 |
| RGB data | D10 | GP3 |

The default keymap is:

| Undo | Copy | Paste |
|---|---|---|
| Previous track | Play/Pause | Next track |
| Escape | Windows screenshot | Delete |

Turning the encoder changes the system volume. The encoder's push contacts are not connected in this PCB revision, so pressing the knob does not generate an input.

The first QMK build exposed an outdated RGB LED configuration name. I replaced `RGBLED_NUM` with `RGBLIGHT_LED_COUNT`, rebuilt the firmware, and successfully produced `jampad_default.uf2`.

## July 1, 2026 — Electrical verification

A schematic-parity check found that one pad on each matrix diode had not inherited its intended switch net. A normal DRC did not flag this as an unrouted connection because each affected net only contained one assigned pad.

I updated the PCB from the schematic and repaired the nine switch-to-diode routes:

- SW1–D2, SW2–D3, SW3–D4
- SW4–D5, SW5–D6, SW6–D7
- SW7–D8, SW8–D9, SW9–D10

After the repair, KiCad reported zero unconnected pads, no diode net conflicts, and no copper-clearance errors. I regenerated the Gerbers and drill files from the corrected board.

## July 1, 2026 — Submission preparation

I organized the project into CAD, PCB, Firmware, production, and assets folders. I added:

- KiCad source files
- QMK source and compiled UF2 firmware
- Gerbers and drill files
- Complete assembly and individual case STEP files
- Project screenshots
- A bill of materials
- A README and ship-post draft

## July 3, 2026 — Hackboard V3

I updated the Fusion 360 assembly and saved the latest editable model as `CAD/Hackboard_V3.f3z`. The repository keeps the STEP exports alongside the native Fusion archive so the design remains both editable and easy to review.

## Current status

The project now includes the complete PCB design, production files, enclosure models, firmware, documentation, and updated CAD source. The next physical steps are PCB fabrication, case printing, soldering, flashing the firmware, and testing every input on the assembled Jampad.

## Lessons learned

- Run schematic-parity checks in addition to normal PCB DRC.
- Keep imported CAD parts grouped before moving or aligning an assembly.
- Check mechanical clearances using the real component models.
- Preserve editable source files as well as manufacturing exports.
- Compile firmware early enough to catch configuration changes before assembly.

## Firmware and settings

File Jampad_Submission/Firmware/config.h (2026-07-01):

#pragma once

/* XIAO RP2040 D4/D5 use RP2040 I2C1 on GP6/GP7. */
#define I2C_DRIVER I2CD1
#define I2C1_SDA_PIN GP6
#define I2C1_SCL_PIN GP7

/* 0.91-inch SSD1306 OLED from the KiCad schematic. */
#define OLED_DISPLAY_128X32
#define OLED_DISPLAY_ADDRESS 0x3C
#define OLED_BRIGHTNESS 128
#define OLED_TIMEOUT 60000

/* EC11-style encoder. Change to 2 if one detent produces two actions. */
#define ENCODER_MAP_KEY_DELAY 10

/* One SK6812 MINI-E driven from XIAO D10 / RP2040 GP3. */
#define WS2812_DI_PIN GP3
#define RGBLIGHT_LED_COUNT 1
#define RGBLIGHT_LIMIT_VAL 96
#define RGBLIGHT_DEFAULT_MODE RGBLIGHT_MODE_STATIC_LIGHT
#define RGBLIGHT_DEFAULT_HUE 128
#define RGBLIGHT_DEFAULT_SAT 255
#define RGBLIGHT_DEFAULT_VAL 48
#define RGBLIGHT_SLEEP

/* Hold BOOT while connecting USB to enter the UF2 bootloader. */
#define RP2040_BOOTLOADER_DOUBLE_TAP_RESET
#define RP2040_BOOTLOADER_DOUBLE_TAP_RESET_TIMEOUT 500U

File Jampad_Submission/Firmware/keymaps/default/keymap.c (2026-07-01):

#include QMK_KEYBOARD_H

enum layer_names {
    _BASE
};

/*
 * ┌──────────┬──────────┬──────────┐
 * │ Undo     │ Copy     │ Paste    │
 * ├──────────┼──────────┼──────────┤
 * │ Previous │ Play     │ Next     │
 * ├──────────┼──────────┼──────────┤
 * │ Escape   │ Screenshot│ Delete  │
 * └──────────┴──────────┴──────────┘
 *
 * Encoder: counter-clockwise = volume down; clockwise = volume up.
 */
const uint16_t PROGMEM keymaps[][MATRIX_ROWS][MATRIX_COLS] = {
    [_BASE] = LAYOUT_ortho_3x3(
        C(KC_Z),    C(KC_C),    C(KC_V),
        KC_MPRV,    KC_MPLY,    KC_MNXT,
        KC_ESC,     G(S(KC_S)), KC_DEL
    )
};

#if defined(ENCODER_MAP_ENABLE)
const uint16_t PROGMEM encoder_map[][NUM_ENCODERS][NUM_DIRECTIONS] = {
    [_BASE] = {ENCODER_CCW_CW(KC_VOLD, KC_VOLU)}
};
#endif

#ifdef OLED_ENABLE
bool oled_task_user(void) {
    oled_write_ln_P(PSTR("JAMPAD"), false);
    oled_write_ln_P(PSTR("XIAO RP2040"), false);
    oled_write_ln_P(PSTR("Knob: Volume"), false);

    led_t host_leds = host_keyboard_led_state();
    oled_write_P(PSTR("Caps: "), false);
    oled_write_ln_P(host_leds.caps_lock ? PSTR("ON") : PSTR("off"), false);

    return false;
}
#endif

void keyboard_post_init_user(void) {
#ifdef RGBLIGHT_ENABLE
    rgblight_enable_noeeprom();
    rgblight_mode_noeeprom(RGBLIGHT_MODE_STATIC_LIGHT);
    rgblight_sethsv_noeeprom(128, 255, 48);
#endif
}

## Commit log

2026-07-01 Initial Jampad project
    [Hackboard_v1-B_Cu.gbl, Hackboard_v1-B_Mask.gbs, Hackboard_v1-B_Paste.gbp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]
2026-07-01 Add funding Bom
    [BOM.csv]
